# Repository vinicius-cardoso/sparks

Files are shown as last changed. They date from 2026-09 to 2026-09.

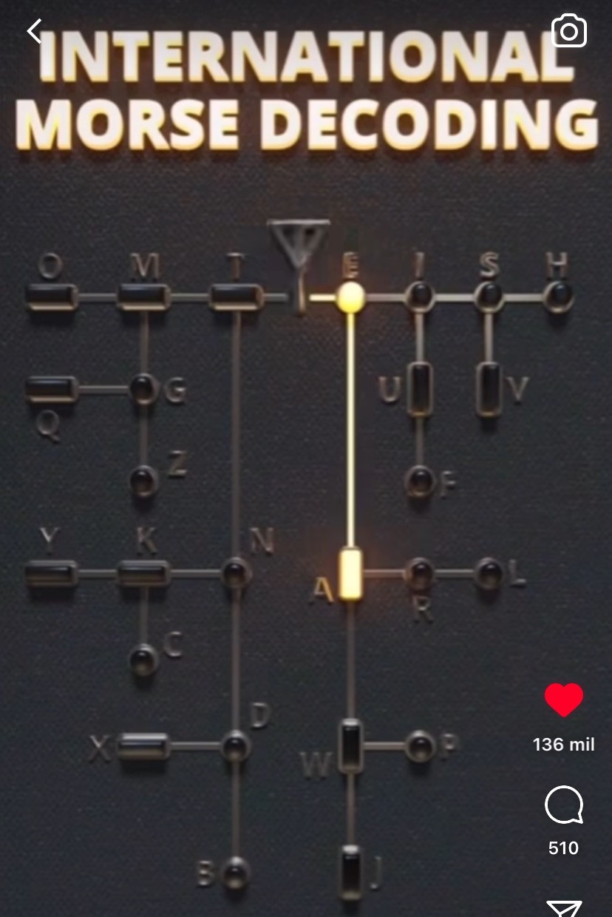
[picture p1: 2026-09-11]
media/morse_code_guide.png

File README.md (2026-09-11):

# Sparks

A handheld Morse code trainer and radio transmitter.

Press the key. The device times your dots and dashes, walks the Morse tree, and
lights the letter you just formed on a 26-LED panel shaped like the tree itself.
Optionally, it keys a CC1101 and sends the same characters over the air.

The panel is the point. Instead of showing you a decoded letter as text, Sparks
shows you *where that letter lives* in the Morse tree — so the structure of the
code becomes something you read off the board rather than something you memorize
from a table.

## The LED panel

The 26 LEDs are not an arbitrary count — they are the International Morse tree for
the English alphabet, one LED per letter. All **white**, so the panel lights
uniformly.

The dot/dash distinction is carried by the **engraved panel**, not by LED colour:
the arm joining each letter to its parent is etched as a **short mark for a dot**
or a **long bar for a dash**, exactly as in `media/morse_code_guide.png`. The code
for any letter is therefore readable by tracing its path from the centre — and
stays readable with the device switched off.

Layout also follows that image: **E** and **T** sit at the centre, **dots branch
right**, **dashes branch left**, and each deeper level branches perpendicular from
its parent.

```
level 1:  E  T                                     2 LEDs
level 2:  I  A  N  M                               4 LEDs
level 3:  S  U  R  W  D  K  G  O                   8 LEDs
level 4:  H  V  F  ·  L  ·  P  J  B  X  C  Y  Z  Q  ·  ·   12 LEDs
                                                  ──────────
                                                   26 LEDs
```

A full four-level tree has 30 slots. The four marked `·` are the non-English
letters (`..--` Ü, `.-.-` Ä, `---.` Ö, `----` CH) and are left empty — deliberate
gaps in the engraved panel, not mistakes.

## Hardware

| Part | Role |
|---|---|
| ESP32-C3 Supermini | the brain — timing, decoding, radio, everything |
| MAX7219 | LED driver — constant current, 3 pins, no series resistors |
| 26 SMD LEDs | the tree panel — all white |
| CC1101 | 433 MHz transceiver (phase 2) |
| Momentary key | Morse input |
| Buzzer | sidetone, so you hear what you send |
| Li-ion cell + TP4056 | power and charging |

The MAX7219 is **not** programmable — it has no CPU. It holds which LEDs are on
and feeds them regulated current; all decisions happen on the ESP32-C3. It exists
so the panel costs 3 GPIOs instead of 26, and so the board needs **one** current-
setting resistor instead of 26 series resistors.

### Pin budget — 11 of 13 GPIOs

| Function | Pins |
|---|---|
| MAX7219 (DIN, CLK, LOAD) | 3 |
| CC1101 (SCK, MISO, MOSI, CS, GDO0) | 5 |
| Morse key | 1 |
| Buzzer | 1 |
| Battery sense (ADC) | 1 |
| **Total** | **11 — 2 spare** |

See `docs/hardware.md` for the wiring detail and the LED addressing map.

> [!NOTE]
> The MAX7219 is a 5 V part and wants ~3.5 V for a logic high. Driving it from a
> 3.3 V ESP32-C3 often works but is marginal. See `docs/hardware.md` for the two
> fixes (level shifter, or run the chip at ~4 V).

## Build phases

1. **Trainer** — LEDs + key + buzzer. No radio. Fully useful on its own, and
   nothing about it raises regulatory questions.
2. **Radio** — populate the CC1101 once the band and power limits are settled.

The CC1101 footprint is on the board from the start; phase 1 simply leaves it
unpopulated.

## Repository layout

```text
.
├── bom/          # bill of materials
├── docs/         # design decisions, hardware notes
├── firmware/     # Arduino sketch (firmware/sparks/sparks.ino)
├── hardware/     # KiCad project, datasheets
├── mechanical/   # Onshape exports, case STEP/STL
└── media/        # reference images, photos
```

## Toolchain

- **KiCad** for the PCB (`hardware/kicad/`)
- **Onshape** for the case, exported to `mechanical/`
- **Fiber laser** to engrave the copper
- **Arduino** for firmware (`firmware/sparks/`)

Keep editable sources as the source of truth: `.kicad_pro`, `.kicad_sch`,
`.kicad_pcb`, `.ino`, native CAD. Generated manufacturing output belongs in
`exports/` directories.

## Status

Early. The existing sketch (`firmware/sparks/sparks.ino`) is a CC1101 bench test
that sends a hardcoded "HELLO" — it predates the panel design and does not yet
decode input or drive the MAX7219.

## Licence

GPL-3.0 — see `LICENSE`.

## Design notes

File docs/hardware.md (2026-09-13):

# Hardware notes

## Block diagram

```
   [KEY] ──────▶ ┌──────────────┐ ──SPI──▶ ┌─────────┐ ──▶ 26 LEDs
                 │  ESP32-C3    │          │ MAX7219 │     (tree panel)
   [BUZZER] ◀─── │  Supermini   │          └─────────┘
                 │              │               │
   [CC1101] ◀──▶ │              │            [RSET]
                 └──────────────┘
                        │
                 [battery sense]
```

The ESP32-C3 does all decision-making: key timing, dot/dash classification, tree
walking, letter identification, gap detection, radio keying, sidetone. The MAX7219
only holds LED state and regulates current — it has no CPU and cannot be
programmed.

## Pin assignment (ESP32-C3 Supermini)

The Supermini breaks out GPIO 0–10, 20, 21 — 13 usable pins.

| GPIO | Function | Notes |
|---|---|---|
| 2 | CC1101 MOSI | |
| 3 | CC1101 SCK | |
| 4 | CC1101 MISO | |
| 1 | CC1101 CS | |
| 0 | CC1101 GDO0 | |
| 5 | MAX7219 DIN | |
| 6 | MAX7219 CLK | |
| 7 | MAX7219 LOAD/CS | |
| 10 | Morse key | `INPUT_PULLUP`, active low |
| 20 | Buzzer | sidetone |
| 21 | Battery sense | ADC via divider |

**Total: 11 of 13 — 2 spare (GPIO8, GPIO9).**

GPIO8/GPIO9 are the strapping pins and the I²C defaults. They are deliberately
left free: they are the least convenient pins to commit, and keeping them open
leaves room for an I²C peripheral later.

Pin numbers above are a starting proposal — adjust during KiCad layout if routing
prefers a different assignment. Only the CC1101 SPI grouping is semi-fixed.

## Power supply — resolved

The board is powered by an **HW-357** combo module: a TP4056 charger and an
MT3608 boost converter on one board, with its own micro-USB socket.

| Module pad | Connects to |
|---|---|
| BAT+ / BAT− | the 102050 LiPo cell |
| OUT+ / OUT− | the `+5V` / `GND` nets |
| IN+ / IN− | **unused** — charging goes through the module's own micro-USB |

This settles the supply question. `+5V` is now a genuine regulated 5 V rather
than raw cell voltage, so the MAX7219 has proper headroom above the white LEDs'
~3.4 V forward drop and the panel stays at constant brightness as the battery
drains.

> [!IMPORTANT]
> The MT3608's output is set by a **trimmer potentiometer** and these boards do
> **not** ship pre-calibrated — some arrive at 10 V or higher. Set it to exactly
> 5.0 V with a multimeter, on its own, **before** connecting it to anything.
> Applying an uncalibrated output to the ESP32-C3 and MAX7219 would destroy both.

**Cost in runtime:** a boost converter draws more current than it supplies, since
it trades voltage for current. Delivering 139 mA at 5 V pulls roughly 190 mA from
a 3.7 V cell, so the 1000 mAh pack gives about 5 hours in trainer mode rather
than 7. The trade buys a panel that stays bright instead of fading.

## MAX7219 logic level — unresolved

The MAX7219 runs at 5 V and specifies `V_IH` ≈ 3.5 V. An ESP32-C3 drives 3.3 V,
which is **below spec**. It frequently works, but it is not a designed-in margin.

Two fixes, both cheap:

1. **Level shifter** on DIN / CLK / LOAD (3 lines, one small part). Keeps the chip
   at 5 V for full LED headroom.
2. **Run the MAX7219 at ~4 V**, lowering `V_IH` to ~2.8 V so 3.3 V logic is
   comfortably valid. Costs some LED drive headroom.

Option 2 is fewer parts; option 1 is more robust. Decide with the board in hand.

The **IS31FL3731** would avoid the question entirely (native 3.3 V, I²C, constant
current, same part count) — but it is SMD-only and effectively import-only in
Brazil, so it is **not** a practical fallback here. If the MAX7219 proves
troublesome at 3.3 V, add the level shifter rather than changing driver.

A suitable shifter is the **TXS0108E** or a **BSS138**-based 4-channel breakout —
both sold locally as ready-made modules.

## LED addressing map

All LEDs are white; the **Final** column records each letter's last symbol, which
is what the engraved arm must show ( · short mark / ▬ long bar ).

The MAX7219 lights whatever LED sits between a SEG and a DIG pin. Physical
position on the panel is **irrelevant** to the chip — the mapping below is
electrical only, and the panel layout follows `media/morse_code_guide.png`.

Rows are grouped by tree level, which keeps the wiring comprehensible:

| Letter | Morse | Final | Level | DIG | SEG |
|---|---|---|---|---|---|
| E | `.` | dot · | 1 | 0 | 0 |
| T | `-` | dash ▬ | 1 | 0 | 1 |
| I | `..` | dot · | 2 | 1 | 0 |
| A | `.-` | dash ▬ | 2 | 1 | 1 |
| N | `-.` | dot · | 2 | 1 | 2 |
| M | `--` | dash ▬ | 2 | 1 | 3 |
| S | `...` | dot · | 3 | 2 | 0 |
| U | `..-` | dash ▬ | 3 | 2 | 1 |
| R | `.-.` | dot · | 3 | 2 | 2 |
| W | `.--` | dash ▬ | 3 | 2 | 3 |
| D | `-..` | dot · | 3 | 2 | 4 |
| K | `-.-` | dash ▬ | 3 | 2 | 5 |
| G | `--.` | dot · | 3 | 2 | 6 |
| O | `---` | dash ▬ | 3 | 2 | 7 |
| H | `....` | dot · | 4 | 3 | 0 |
| V | `...-` | dash ▬ | 4 | 3 | 1 |
| F | `..-.` | dot · | 4 | 3 | 2 |
| L | `.-..` | dot · | 4 | 3 | 4 |
| P | `.--.` | dot · | 4 | 3 | 6 |
| J | `.---` | dash ▬ | 4 | 3 | 7 |
| B | `-...` | dot · | 4 | 4 | 0 |
| X | `-..-` | dash ▬ | 4 | 4 | 1 |
| C | `-.-.` | dot · | 4 | 4 | 2 |
| Y | `-.--` | dash ▬ | 4 | 4 | 3 |
| Z | `--..` | dot · | 4 | 4 | 4 |
| Q | `--.-` | dash ▬ | 4 | 4 | 5 |

Uses DIG0–DIG4 (5 of 8) and SEG0–SEG7. Gaps at DIG3/SEG3, DIG3/SEG5, DIG4/SEG6,
DIG4/SEG7 are the four non-English letters — left unpopulated.

Three DIG lines remain free, so status LEDs (power, TX, charge) can be added later
with no driver change.

## KiCad reference

Verified against the KiCad 10.0.5 stock libraries.

### Symbols available

| Part | Library | Symbol |
|---|---|---|
| MAX7219 | `Driver_LED` | `MAX7219` |
| Battery cell | `Device` | `Battery_Cell` |
| LED / resistor / capacitor | `Device` | `LED` / `R` / `C` |

### Symbols NOT in the stock libraries

These are all boards mounted on headers rather than bare chips, so represent each
with a `Connector_Generic:Conn_01x0N` sized to its pin count:

- **ESP32-C3 Supermini** — stock libs carry only the bare die and the WROOM
  modules, not this board. Two 8-pin headers match its layout.
- **TP4056** — stock libs contain **TP4057**, a *different part*; do not
  substitute it. Use the local `TP4056-Breakout` library instead.
- **CC1101 module** — socketed, not soldered. Use a generic
  `Connector_Generic:Conn_02x04_Odd_Even` symbol with the footprint
  `Connector_PinSocket_2.54mm:PinSocket_2x04_P2.54mm_Vertical`. No dedicated
  symbol is kept: the board only carries the socket, so a generic connector
  describes it accurately.

### Footprints

| Part | Footprint |
|---|---|
| MAX7219 | `Package_DIP:DIP-24_W7.62mm` |
| White LEDs (×26) | `LED_SMD:LED_0805_2012Metric_Pad1.15x1.40mm_HandSolder` |
| Resistors / caps | `Resistor_SMD:R_0805_2012Metric_Pad1.20x1.40mm_HandSolder` |

Two things to get right:

- Use **`W7.62mm`** (300 mil narrow body), *not* the `W15.24mm` variants — those
  are a physically different package.
- Prefer the **`_HandSolder`** variants throughout; their pads are slightly
  extended for manual soldering.

### MAX7219 pinout, and a naming trap

The symbol names the segment outputs `SEG_A`…`SEG_G` plus `SEG_DP`, because the
chip was designed for seven-segment displays. For Sparks they are just eight
generic outputs. Mapping to the addressing table above:

| Table | Symbol pin | Pin № |
|---|---|---|
| SEG0 | `SEG_A` | 14 |
| SEG1 | `SEG_B` | 16 |
| SEG2 | `SEG_C` | 20 |
| SEG3 | `SEG_D` | 23 |
| SEG4 | `SEG_E` | 21 |
| SEG5 | `SEG_F` | 15 |
| SEG6 | `SEG_G` | 17 |
| SEG7 | `SEG_DP` | 22 |

`DIG_0`…`DIG_7` map directly; Sparks uses DIG_0–DIG_4.

**Pin 18 is `ISET`** — this is `RSET` elsewhere in these notes. It connects to
**V+**, not to ground.

### Connections

```
ESP32-C3           MAX7219
GPIO5  ──────────▶ DIN   (pin 1)
GPIO6  ──────────▶ CLK   (pin 13)
GPIO7  ──────────▶ LOAD  (pin 12)
                   ISET  (pin 18) ──[RSET]── V+
                   V+    (pin 19) ── 5 V
                   GND   (pins 4 AND 9)
```

LED **anodes → SEG** pins, **cathodes → DIG** pins.

> [!WARNING]
> Connect **both** ground pins (4 and 9). Leaving one floating is a common
> omission and causes erratic, hard-to-diagnose behaviour.

## Panel layout and engraving

From `media/morse_code_guide.png`:

- **E** and **T** at the centre, flanking the root.
- **Dots branch right**, **dashes branch left**.
- Each deeper level branches perpendicular from its parent, producing the
  cross/grid arrangement rather than a conventional top-down tree.
- Engraved arms connect parent to child, so the path spelling each letter is
  physically traceable on the panel.

### The arms carry the dot/dash information

Since the LEDs are all white, the engraving is now the **only** thing encoding
dot vs dash — so it has to be unambiguous:

- a **dot** arm is engraved as a short mark ( · )
- a **dash** arm is engraved as a long bar ( ▬ )

This matches the reference image, where the arms are visibly different lengths.
Make the long bar at least 3× the short mark, mirroring Morse timing itself, so
the difference is obvious at a glance rather than something to measure.

Each letter is also labelled. Tracing from the centre outward and reading the arms
gives the letter's code directly — and unlike LED colour, it stays readable with
the device switched off, which makes the panel useful as a static reference chart.

## CC1101 module and antenna

The module on hand is the **V2.0 SMA variant**, marked `433M`, with a gold SMA
female socket on the board edge. It ships with a short black whip antenna carrying
a male SMA plug, which **screws onto** that socket.

The antenna is therefore **detachable, not built in** — the two simply come in the
same bag. Nothing to buy, but the mechanical design has to account for it:

- The SMA socket sticks out from the module's edge and is rigid. It sets a hard
  constraint on where the CC1101 can sit inside the case.
- The case needs either an opening for the whip, or an internal antenna position
  with the whip removed. Antennas do not work well inside a sealed enclosure,
  especially near a copper ground plane.
- A panel-mount SMA extension (pigtail) is the usual fix: socket on the case wall,
  short coax to the module. Adds a part but frees the module's placement.
- The whip is removable, so it can be unscrewed for storage — worth designing for
  if the device is meant to be pocketable.

**Never key the transmitter with the antenna unscrewed.** With nothing to radiate
into, power reflects back into the PA and can damage it. For bench testing without
emitting, use a 50 Ω dummy load in place of the whip.

## LEDs — all white

All 26 LEDs are white. This was a deliberate simplification: a single colour means
a single Vf and a single efficiency, so the one `RSET` the MAX7219 allows suits
every LED and the panel lights uniformly.

(The earlier design used 14 red + 12 green to encode each letter's final symbol.
That mapping is still *true* — see `docs/decisions.md` §1 for why the count is 26
— but it is now expressed by the engraved panel rather than by LED colour.)

**Sourcing:** buy all 26 from a single reel or batch. Bin-to-bin variation within
one colour is small but visible on a panel where LEDs sit side by side.

> [!IMPORTANT]
> White LEDs have a **high forward voltage: ~2.8–3.4 V**, considerably more than a
> red LED's ~2.0 V. This bears directly on the MAX7219 supply question in
> *MAX7219 logic level* above — the chip needs headroom above Vf to drive current
> properly. It argues for running the MAX7219 at **5 V** rather than the ~4 V
> option, which in turn makes the level shifter on DIN/CLK/LOAD the likely choice.
> Verify on the breadboard before committing to either.

## Power budget

Estimated worst case. The MAX7219 multiplexes one digit row at a time, so the
instantaneous draw is set by the **largest row**, not by all 26 LEDs at once.

| Digit row | LEDs | Peak @20 mA/LED |
|---|---|---|
| DIG0 | 2 | 40 mA |
| DIG1 | 4 | 80 mA |
| DIG2 | 8 | **160 mA** ← worst row |
| DIG3 | 6 | 120 mA |
| DIG4 | 6 | 120 mA |

- **Worst instantaneous:** ~160 mA (DIG2, the level-3 row — all 8 letters)
- **Average panel draw, everything "lit":** ~104 mA at 20% duty per row

Adding the rest:

| Load | Draw |
|---|---|
| Panel (average) | ~104 mA |
| ESP32-C3 active | ~30 mA |
| MAX7219 quiescent | ~5 mA |
| CC1101 TX @ 10 dBm | ~35 mA |
| Buzzer | ~20 mA |

- **Trainer mode (no radio): ~139 mA**
- **TX mode (worst case): ~194 mA**

### Battery sizing

| Cell | Trainer | TX |
|---|---|---|
| 500 mAh pouch | 3.6 h | 2.6 h |
| 1000 mAh pouch | 7.2 h | 5.2 h |
| 18650 2000 mAh | 14.4 h | 10.3 h |
| 18650 3000 mAh | 21.6 h | 15.5 h |

These are pessimistic — they assume the panel is fully lit continuously, which it
never is. In real use only a few LEDs light at a time and the device sleeps
between key presses, so expect substantially better. **Any cell ≥1000 mAh is
comfortable**; pick on physical size for the case rather than on capacity.

Lowering `RSET` to run the LEDs at 10 mA instead of 20 mA roughly halves the panel
draw and is likely still plenty bright indoors.

## Power

- Li-ion cell (18650 or pouch) + TP4056 charge module with protection.
- ESP32-C3 Supermini has an onboard regulator and accepts battery voltage at 5V/VIN.
- MAX7219 supply depends on the logic-level decision above.
- Battery sense: resistor divider into an ADC pin. Size it so the divider current
  is negligible, and consider a MOSFET to disconnect it during sleep.

## Fabrication

Copper engraved with a fiber laser. Relevant consequences:

- Trace count matters more than usual — every trace is engraving time and a
  potential defect. The MAX7219 keeps this to ~16 panel traces.
- **MAX7219 package: DIP-24**, chosen for soldering ease. Pin pitch is 2.54 mm
  against SOIC-24's 1.27 mm, the pads are large, and through-hole joints are
  soldered from the underside with room to work — solder bridges are very hard to
  create. This also sidesteps needing to characterise the laser's minimum
  trace/space, since 2.54 mm is comfortable for any fiber laser.
- Cost: the DIP body is ~32 × 8 mm and needs 24 drilled holes. Acceptable here
  because the 26-LED tree already sets the board size, not the driver IC.
- The **LEDs remain SMD** (0805). They are simple two-pad parts — much easier than
  a fine-pitch IC — and SMD keeps them flush against the panel surface, which
  matters for how the engraved tree reads.

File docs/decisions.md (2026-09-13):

# Design decisions

A record of what was chosen, what was rejected, and why. Written so the reasoning
survives — if a decision gets revisited, the tradeoff is here rather than being
re-derived from scratch.

## 1. The 26 LEDs are the Morse tree

**Decision:** one LED per letter, arranged as the dichotomic Morse tree from
`media/morse_code_guide.png`. **All LEDs white** (revised — see §1a).

A full four-level tree holds 30 letters; the 4 unused slots (`..--`, `.-.-`,
`---.`, `----`) are non-English letters and stay empty on the panel.

### Where the number 26 came from

The original specification was 14 red + 12 green, and those counts turned out to
be exact rather than arbitrary. Colouring each letter by its **final** symbol
splits the English alphabet precisely:

- dot-final, 14: `B C D E F G H I L N P R S Z`
- dash-final, 12: `A J K M O Q T U V W X Y`

This is what identified the panel as the Morse tree in the first place, and it
still explains why there are 26 LEDs. The relationship is real; only its *visual
expression* changed in §1a.

**Why the shape matters:** the panel's arrangement is the teaching mechanism. Any
option that forced a different physical layout was rejected on that basis alone.

## 1a. Revised: all LEDs white, dot/dash engraved instead

**Decision:** all 26 LEDs white; the dot/dash distinction moves from LED colour
to the **engraved arms** — short mark for a dot, long bar for a dash.

**Why:**

- **One colour, one `RSET`.** The MAX7219 allows a single current-setting resistor
  for all LEDs. Red (~2.0 V) and green (~2.0–3.2 V) differ in Vf and efficiency, so
  under one `RSET` they would not have matched in brightness — and per-digit
  intensity control could not fix it, since the colours were mixed across rows.
  A single colour eliminates the problem entirely.
- **Simpler sourcing.** One part number, one reel, uniform output.
- **The information is not lost.** Engraving carries it permanently, and unlike LED
  colour it is readable with the device switched off — so the panel doubles as a
  static reference chart.

**Tradeoff accepted:** no at-a-glance colour cue for "this letter ends long". The
engraved arm lengths convey it instead, which requires tracing rather than
glancing.

**Consequence to watch:** white LEDs have a high forward voltage (~2.8–3.4 V),
which pushes toward running the MAX7219 at 5 V for headroom — and therefore toward
needing the level shifter. See `docs/hardware.md`.

## 2. Some LED driver is mandatory — this is arithmetic, not preference

Fixed peripheral cost is 8 pins (CC1101 SPI ×4 + GDO0, key, buzzer, battery ADC).
Against that:

| Board | GPIO | Free after peripherals | Direct 26 LEDs? |
|---|---|---|---|
| ESP32-C3 Supermini | 13 | 5 | no — short 21 |
| Arduino Nano | 20 | 12 | no — short 14 |
| Raspberry Pi Pico | 26 | 18 | no — short 8 |
| ESP32 DevKit V1 | 25 | 17 | no — short 9 |

**No board on hand can drive 26 LEDs directly**, not even the Pico. Switching
boards does not dissolve the constraint, which is why the MCU choice was freed to
be decided on other merits.

## 3. Driver: MAX7219

Ranked by **physical build work** (firmware cost excluded — it's written, not
soldered):

| Option | Parts to place | Joints | Brightness |
|---|---|---|---|
| **MAX7219** | **4** | 82 | full, dimmable |
| Pico charlieplex | 6 | 64 | dim — 3.8% duty |
| 4× 74HC595 | 34 | 176 | full |
| WS2812B | 52 | 156 | full |

**Chosen: MAX7219.** Constant-current drive means **one** `RSET` resistor sets
brightness for all 26 LEDs, eliminating 26 series resistors — 26 fewer parts to
place *and* 26 fewer traces to route and laser-etch.

**Rejected:**

- **74HC595 ×4** — was the initial recommendation while firmware simplicity still
  counted as a cost. Once firmware became free, 34 parts vs 4 ended it. Still a
  reasonable fallback: easier to source, and already stocked locally.
- **Charlieplexing** — 6 pins for 30 LEDs and the fewest parts, but lights one LED
  at a time: 3.8% duty. Matching a static 5 mA LED would need ~130 mA peak against
  an ~8 mA/pin RP2040 spec. For a device whose whole purpose is *being read*, a dim
  panel is disqualifying.
- **WS2812B** — one pin and per-LED colour in software, but abandons the specified
  red/green SMD LEDs, needs a decoupling cap per LED (52 parts), and draws far more
  from the battery.

### Clarification worth keeping

"Matrix" here means the **electrical addressing scheme** (which SEG/DIG pin pair
addresses each LED), *not* a physical square. The MAX7219 exposes 8 SEG + 8 DIG
pins and lights whatever LED sits between a pair — it has no knowledge of where
that LED physically sits. The tree layout is therefore completely unconstrained by
the driver choice.

The off-the-shelf "8×8 MAX7219 module" is a *product built around* the chip, with
LEDs pre-soldered in a grid. Not what is used here — Sparks uses the bare IC.

## 4. Board: ESP32-C3 Supermini

Every candidate fits once a driver is used, so this was decided on other grounds:

- **3.3 V native** — wires directly to the CC1101. The Arduino Nano is 5 V and
  would need level shifting on every SPI line to avoid damaging the radio.
- **Smallest footprint** for a handheld case.
- **USB-C**, good deep sleep for Li-ion.
- The existing sketch already targets it.

**Rejected:** Pico (only compelling for charlieplexing, which lost on brightness;
larger board), ESP32 DevKit V1 (largest, worst idle current), Nano (5 V mismatch).

## 5. No OLED

The existing bench sketch drives an SSD1306, but the 26-LED tree *is* the display.
Dropping it removes a part, a case cutout, and frees GPIO8/GPIO9 — the strapping
pins, which are the least convenient pins to spend anyway.

**Tradeoff accepted:** no text readout, so no WPM, battery percentage, or decoded
letter as an actual character. Reading the tree is the intended skill.

## 6. Radio: trainer first

Phase 1 ships without RF. The CC1101 footprint is on the board but unpopulated,
so the trainer is immediately buildable and usable while band and power limits are
settled separately.

**Open:** the legal position for 433 MHz short-range transmission in Brazil
(ANATEL) has not been researched yet. Do that before populating the radio.

## 7. CC1101 antenna is detachable, not built in

**Finding, not a decision:** the module on hand is the **V2.0 SMA variant** (gold
SMA socket on the board edge, `433M` silkscreen). It ships with a short whip
carrying a male SMA plug, which screws on. The two arrive in the same bag, which
is easy to read as "the antenna is built in" — it is not.

**Consequences:** nothing to buy, but the whip is a rigid protruding part that
constrains where the CC1101 can sit in the case, and antennas work poorly inside a
sealed enclosure next to a copper ground plane. A panel-mount SMA pigtail is the
usual fix. See `docs/hardware.md`.

**Safety:** never key the transmitter with the whip unscrewed — power reflects back
into the PA. Use a 50 Ω dummy load for bench testing.

## 8. The panel needs a double-sided board

**Finding.** Routing the 26-LED matrix on a single layer requires roughly **56
jumper wires**, measured by taking each net's minimum spanning tree and counting
straight-line crossings between nets.

**Why.** The matrix is organised by tree *level* — DIG0 is level 1, DIG3 holds
six of the level-4 letters — while the panel is organised by tree *geometry*,
where those same six letters (J, P, F, L, V, H) sit scattered across four rows on
opposite sides of the board. The electrical grouping and the visual arrangement
are different organisations of the same 26 parts, and they do not reconcile on
one layer.

Total net length is about 823 mm across 13 nets.

**Decision:** route double-sided. DIG nets on the back under the panel, SEG nets
on the front between the LEDs, crossings resolved with vias rather than soldered
jumpers. The MAX7219 mounts on the back, centred beneath the panel, which also
shortens its 16 traces.

**Rejected:** single-sided with jumpers — 25-30 hand-soldered wires even after
optimisation, on the visible face of a handheld device. Rejected on both build
effort and appearance.

**Also rejected:** rearranging the panel so electrical rows match visual rows.
That would route trivially on one layer but abandons the tree shape, which is the
device's entire purpose.

**Consequence for fabrication:** the fiber laser must etch both faces with
registration between them. Add alignment holes to the board outline before
etching.

## Open items

- **MAX7219 at 3.3 V.** The chip is a 5 V part wanting ~3.5 V for a logic high.
  Often works directly from a 3.3 V MCU; not reliable enough to design around. Fix
  with a level shifter on DIN/CLK/LOAD, or run the chip at ~4 V. Decide with the
  real board in hand. The **IS31FL3731** was the considered alternative — natively
  3.3 V, I²C, same part count — but MAX7219 was chosen for availability.
- **ANATEL limits** for 433 MHz (see §6).
- **LED forward voltage** vs MAX7219 headroom — check once the exact LEDs are
  picked, since it sets `RSET`.

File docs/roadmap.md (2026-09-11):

# Roadmap

Ordered so that each step produces something testable, and so the parts that are
still undecided stay off the critical path.

## Phase 0 — settle the unknowns (no hardware needed)

- [ ] Pick the exact white LEDs; record Vf. Buy all 26 from one reel/batch.
      **White Vf is high (~2.8–3.4 V) — check MAX7219 supply headroom.**
- [ ] Compute `RSET` from Vf and target current.
- [ ] Design the engraved arms: short mark = dot, long bar = dash, ≥3:1 ratio.
      With white LEDs this engraving is the *only* dot/dash cue.
- [x] Estimate worst-case current → see `docs/hardware.md` § Power budget.
      Trainer ~139 mA, TX ~194 mA worst case; any cell ≥1000 mAh is comfortable.
- [ ] Decide MAX7219 supply voltage → level shifter required or not.
- [x] MAX7219 package → **DIP-24**, chosen for hand-soldering ease. 2.54 mm pitch
      is within any fiber laser's capability, so the minimum trace/space question
      no longer blocks the design.

## Phase 1 — breadboard the panel

- [ ] MAX7219 + a handful of LEDs on a breadboard, driven by the ESP32-C3.
- [ ] Confirm 3.3 V logic actually clocks the chip reliably (this is the open risk).
- [ ] Firmware: light an arbitrary LED by letter — proves the SEG/DIG map.

## Phase 2 — the trainer firmware

- [ ] Key timing: debounce, classify dot vs dash by duration.
- [ ] Walk the tree as symbols arrive; light the current node live.
- [ ] Letter gap → commit the letter. Word gap → space.
- [ ] Buzzer sidetone keyed with the input.
- [ ] Adaptive timing, so the dot/dash threshold follows the user's speed.

At this point Sparks is fully useful without a PCB or a radio.

## Phase 3 — PCB

- [ ] Schematic in KiCad.
- [ ] Panel layout matching `media/morse_code_guide.png` — this is the hard part;
      the LED positions are fixed by the tree, routing works around them.
- [ ] Route; keep trace count low for the laser.
- [ ] Engrave, populate, test.

## Phase 4 — case

- [ ] Onshape model around the finished board.
- [ ] Front panel with the tree engraved — arms connecting parent to child.
- [ ] Export STEP/STL to `mechanical/`.

## Phase 5 — radio

- [ ] Research ANATEL limits for 433 MHz short-range in Brazil. **Blocking.**
- [ ] Populate the CC1101; test into a dummy load first.
- [ ] Key the radio in step with the LED panel and sidetone.
- [ ] Decide on a receive mode — decoding incoming Morse onto the same panel would
      be a natural extension.

## Ideas, unscheduled

- Playback mode: the device sends a letter, you copy it — reverse training.
- Speed/WPM readout using the spare DIG lines as a small status row.
- Store practice statistics; which letters you get wrong most.

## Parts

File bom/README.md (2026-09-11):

# Bill of materials

`bom.csv` is the working BOM. Columns:

- **status** — `have` / `to buy` / `to make` / `conditional` / `phase 2`
- **notes** — anything that would otherwise be lost between sessions

## Sourcing: Brazil

Parts are chosen to be buyable locally (Mercado Livre, national distributors)
rather than imported. This is a selection criterion, not an afterthought — a part
that is optimal on paper but import-only costs weeks and customs hassle.

**Consequences already baked into this BOM:**

- **MAX7219 in DIP-24**, not SOIC. The DIP is the common hobby part sold
  everywhere here; the SMD version is the awkward one to find. (DIP was already
  chosen for soldering ease — the two criteria agree.)
- **IS31FL3731 rejected as a fallback.** Technically the better driver, but
  SMD-only and effectively import-only. If the MAX7219 struggles at 3.3 V, add a
  level shifter instead of changing driver.
- **Level shifter named explicitly** — TXS0108E or a BSS138 breakout, both sold
  locally as ready-made modules.

**Watch out for:** the 26 white 0805 LEDs. Buying locally often means loose parts
from mixed bins rather than one reel, and bin-to-bin variation is visible when the
LEDs sit side by side on a panel. Buy 40–50 from a **single seller and lot**, then
pick the 26 most consistent. The spares also cover soldering mishaps.

## Things to resolve before ordering

1. **LED forward voltage.** Sets `RSET` (R1) and therefore panel brightness. Red
   and green differ, and the MAX7219 uses one `RSET` for all — so the two colours
   will not match in brightness by default. Check Vf for both and decide whether
   the mismatch is acceptable or needs compensating.
2. **Total current with all 26 lit.** Sets battery capacity. Not yet estimated.
3. **MAX7219 package.** DIP-24 is far easier to fiber-laser than SOIC-24. Confirm
   the minimum pitch the laser holds before committing.
4. **Logic level.** If the MAX7219 runs at 5 V, the level shifter becomes
   required, not conditional. See `docs/hardware.md`.

## Phase 1 vs phase 2

Phase 1 (trainer) needs everything except U3 (CC1101) and J1 (antenna). The radio
footprint is on the board from the start and simply stays unpopulated, so phase 1
is buildable without settling any regulatory question.

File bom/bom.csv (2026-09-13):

ref | qty | part | value | package | role | status | notes
U1 | 1 | ESP32-C3 Supermini |  | module | MCU — all timing/decoding/radio control | have | 13 GPIO broken out (0-10 20 21); 3.3V native
U2 | 1 | MAX7219 |  | DIP-24 | LED driver — constant current 3-wire | to buy | DIP chosen for hand-soldering: 2.54mm pitch vs 1.27mm SOIC. 5V part; see docs/hardware.md logic-level note
U3 | 1 | CC1101 module V2.0 | 433 MHz | module + SMA socket | RF transceiver | have | phase 2; SMA variant with detachable whip. SOCKETED not soldered — plugs into J2 when radio is in use
J2 | 1 | Pin socket 2x4 female | 2.54mm | PinSocket_2x04_P2.54mm_Vertical | CC1101 module socket | to buy | female socket on the PCB; module's male pins plug in. Symbol: Conn_02x04_Odd_Even (generic — no dedicated CC1101 symbol needed)
D1-D26 | 26 | SMD LED white |  | 0805 | one per letter of the Morse tree | to buy | ALL WHITE — single Vf so one RSET suits every LED. BUY EXTRA (40-50) FROM ONE SELLER/LOT — mixed bins show as uneven brightness side by side. White Vf ~2.8-3.4V — check MAX7219 headroom.
R1 | 1 | Resistor | ~10k | 0805 | RSET — sets LED current for ALL 26 LEDs | to buy | exact value depends on LED Vf and target brightness
R2 | 1 | Resistor | 220k | 0805 | battery divider high side | to buy | battery divider high side; R2=R3 halves Vbat into ADC range. 220k => ~9.5uA drain
R3 | 1 | Resistor | 220k | 0805 | battery divider low side | to buy | battery divider low side; midpoint to GPIO21. Keep <500k or ADC reads drift
C1 | 1 | Capacitor | 100nF | 0805 | MAX7219 decoupling | to buy | place close to the IC
C2 | 1 | Capacitor | 10uF | 0805 | MAX7219 bulk | to buy
C3 | 1 | Capacitor | 100nF | 0805 | ESP32-C3 decoupling | to buy
SW1 | 1 | Tactile switch 6x6mm |  | SW_PUSH_6mm (THT, 4-pin) | Morse key | to buy | classic 6x6 tact switch; 4 pins but only 2 nets. Pick _H5mm variant if button height matters for the case
SW2 | 1 | Slide switch |  | SMD | power on/off | to buy
BZ1 | 1 | Magnetic buzzer 12mm |  | Buzzer_12x9.5RM7.6 (THT) | sidetone — hear what you send | to buy | 12mm dia, 9.5mm tall, 7.6mm pin pitch. ACTIVE buzzer = fixed tone; PASSIVE needed for tone() sidetone — see docs
BT1 | 1 | LiPo pouch 102050 | 3.7V 1000mAh | SolderWire 1x02 P3.7mm (flying leads) | power | to buy | 10x20x50mm, 1000mAh = ~5h trainer / ~3.5h TX via boost (boost draws ~190mA from cell for 139mA at 5V). Flying leads soldered to pads; use _Relief variant for strain relief
M1 | 1 | HW-357 TP4056+MT3608 module | 5V out | module w/ micro-USB | charging + protection + 5V boost | have | combo board: TP4056 charger + MT3608 boost. Charge via its own micro-USB; IN+/IN- unused. SET TRIMMER TO 5.0V BEFORE CONNECTING - ships uncalibrated
J1 | 1 | Antenna whip | 433 MHz | SMA male stub | RF | have | ships with the module; screws onto the board SMA socket. Detachable — case needs an opening. Never key the radio without it or a dummy load.
 | 1 | Level shifter TXS0108E or BSS138 |  | breakout module | 3.3V to 5V for MAX7219 DIN/CLK/LOAD | conditional | only if running MAX7219 at 5V — see docs/hardware.md. Both sold as modules in BR
 | 1 | PCB |  |  | main board | to make | fiber-laser engraved copper
 | 1 | Enclosure |  |  | case | to make | Onshape; exports to mechanical/

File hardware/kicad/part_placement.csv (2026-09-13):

ref | x_mm | y_mm | rot | layer | note
J1 | 150.0 | 100.0 | 90 | front | CC1101 socket at top edge, ROT 90 so the 4-pin row runs along X and the antenna points UP away from user
U1 | 150.0 | 129.0 | 0 | back | MAX7219 on back, centred under panel
R1 | 132.0 | 156.0 | 0 | back | RSET, back
C1 | 135.0 | 156.0 | 0 | back | 100nF MAX7219, back
C2 | 138.0 | 156.0 | 0 | back | 10uF bulk, back
BZ1 | 129.0 | 161.0 | 0 | front | buzzer
BT1 | 176.0 | 157.0 | 0 | front | battery pads
R2 | 168.0 | 157.0 | 0 | front | battery divider
R3 | 171.0 | 157.0 | 0 | front | battery divider
C3 | 150.0 | 157.0 | 0 | front | 100nF ESP32
U2 | 137.0 | 180.0 | 0 | front | ESP32-C3
J2 | 168.0 | 175.0 | 0 | front | HW-357 power module
SW1 | 155.0 | 188.0 | 0 | front | Morse key

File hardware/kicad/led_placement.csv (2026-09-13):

ref | letter | morse | x_mm | y_mm | dig | seg
D1 | E | . | 150.00 | 108.00 | 0 | 0
D2 | T | - | 142.00 | 108.00 | 0 | 1
D3 | I | .. | 158.00 | 108.00 | 1 | 0
D4 | A | .- | 150.00 | 129.00 | 1 | 1
D5 | N | -. | 142.00 | 129.00 | 1 | 2
D6 | M | -- | 134.00 | 108.00 | 1 | 3
D7 | S | ... | 166.00 | 108.00 | 2 | 0
D8 | U | ..- | 158.00 | 115.00 | 2 | 1
D9 | R | .-. | 158.00 | 129.00 | 2 | 2
D10 | W | .-- | 150.00 | 143.00 | 2 | 3
D11 | D | -.. | 142.00 | 143.00 | 2 | 4
D12 | K | -.- | 134.00 | 129.00 | 2 | 5
D13 | G | --. | 134.00 | 115.00 | 2 | 6
D14 | O | --- | 126.00 | 108.00 | 2 | 7
D15 | H | .... | 174.00 | 108.00 | 3 | 0
D16 | V | ...- | 166.00 | 115.00 | 3 | 1
D17 | F | ..-. | 158.00 | 122.00 | 3 | 2
D18 | L | .-.. | 166.00 | 129.00 | 3 | 4
D19 | P | .--. | 158.00 | 143.00 | 3 | 6
D20 | J | .--- | 150.00 | 150.00 | 3 | 7
D21 | B | -... | 142.00 | 150.00 | 4 | 0
D22 | X | -..- | 134.00 | 143.00 | 4 | 1
D23 | C | -.-. | 134.00 | 136.00 | 4 | 2
D24 | Y | -.-- | 126.00 | 129.00 | 4 | 3
D25 | Z | --.. | 134.00 | 122.00 | 4 | 4
D26 | Q | --.- | 126.00 | 115.00 | 4 | 5

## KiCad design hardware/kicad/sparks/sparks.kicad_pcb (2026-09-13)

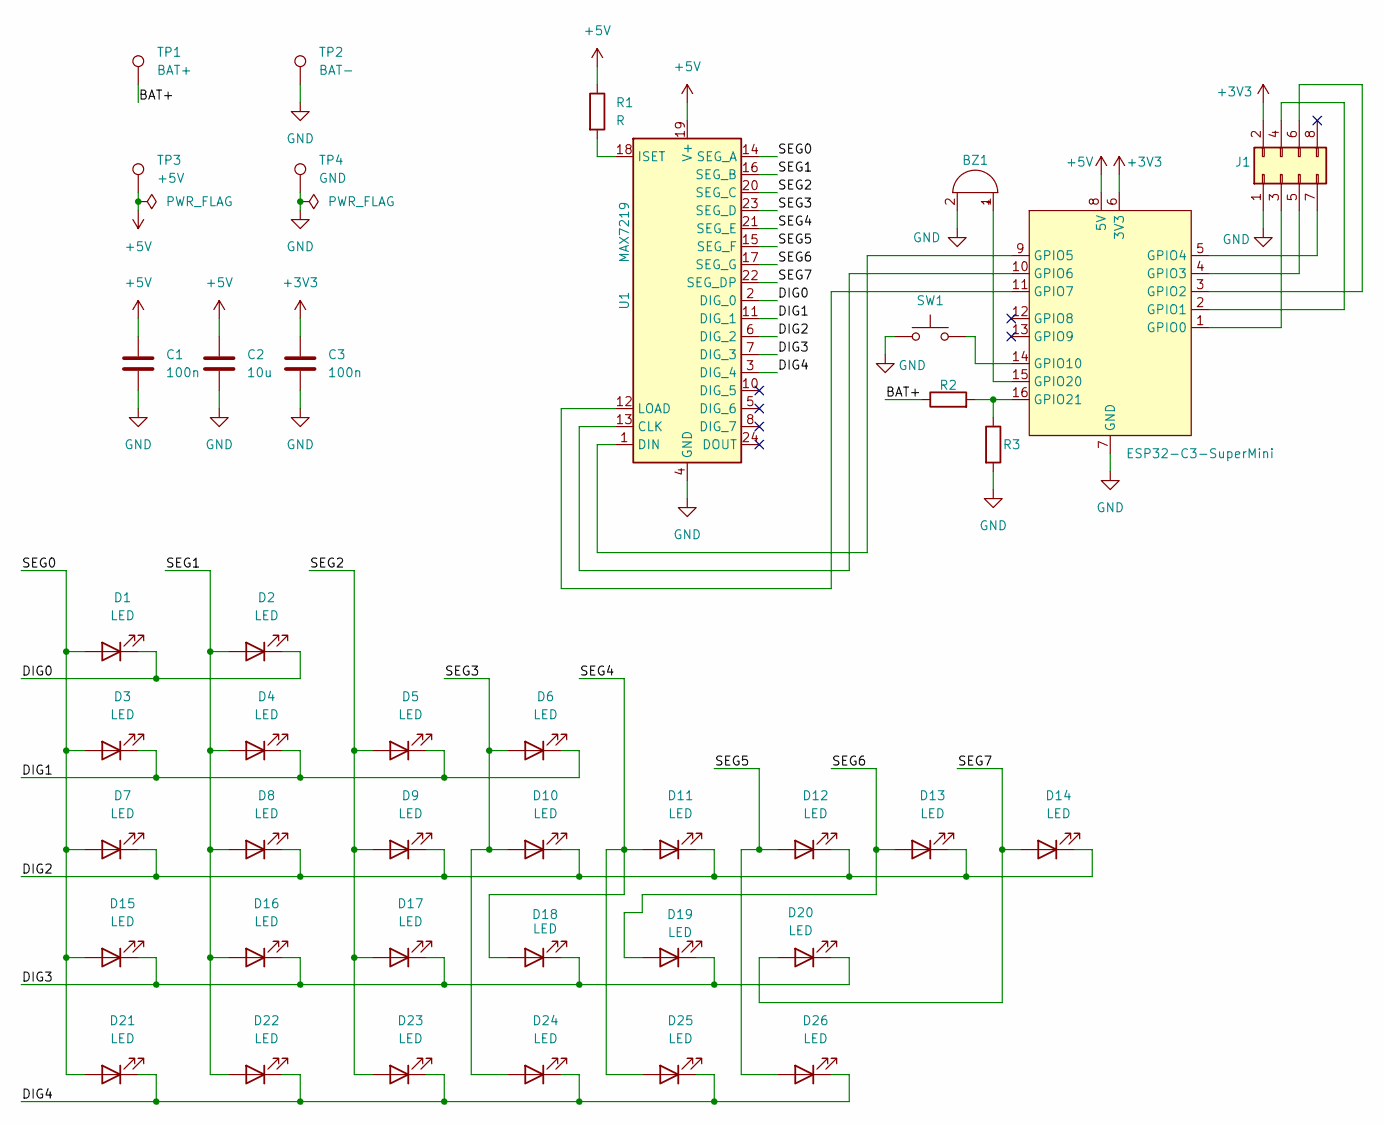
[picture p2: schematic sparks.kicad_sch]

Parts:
BZ1: Buzzer; Buzzer_12x9.5RM7.6
C1, C3: 100n; C_0805_2012Metric_Pad1.18x1.45mm_HandSolder
C2: 10u; C_0805_2012Metric_Pad1.18x1.45mm_HandSolder
D1, D2, D3, D4, D5, D6, D7, D8, D9, D10, D11, D12, D13, D14, D15, D16, D17, D18, D19, D20, D21, D22, D23, D24, D25, D26: LED; LED_0805_2012Metric_Pad1.15x1.40mm_HandSolder
J1: Conn_02x04_Odd_Even; PinHeader_2x04_P2.54mm_Vertical
R1: R; R_0805_2012Metric_Pad1.20x1.40mm_HandSolder
R2, R3: 220k; R_0805_2012Metric_Pad1.20x1.40mm_HandSolder
SW1: SW_Push; SW_PUSH_6mm
TP1: BAT+; TestPoint_THTPad_2.0x2.0mm_Drill1.0mm
TP2: BAT-; TestPoint_THTPad_2.0x2.0mm_Drill1.0mm
TP3: +5V; TestPoint_THTPad_2.0x2.0mm_Drill1.0mm
TP4: GND; TestPoint_THTPad_2.0x2.0mm_Drill1.0mm
U1: MAX7219; SOIC-24W_7.5x15.4mm_P1.27mm
U2: ESP32-C3-SuperMini

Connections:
+3V3: C3.1, J1.2, U2.6 (3V3)
+5V: C1.1, C2.1, R1.1, TP3.1 (1_1), U1.19 (V+), U2.8 (5V)
/BAT+: R2.1, TP1.1 (1_1)
/DIG0: D1.1 (K), D2.1 (K), U1.2 (DIG_0)
/DIG1: D3.1 (K), D4.1 (K), D5.1 (K), D6.1 (K), U1.11 (DIG_1)
/DIG2: D7.1 (K), D8.1 (K), D9.1 (K), D10.1 (K), D11.1 (K), D12.1 (K), D13.1 (K), D14.1 (K), U1.6 (DIG_2)
/DIG3: D15.1 (K), D16.1 (K), D17.1 (K), D18.1 (K), D19.1 (K), D20.1 (K), U1.7 (DIG_3)
/DIG4: D21.1 (K), D22.1 (K), D23.1 (K), D24.1 (K), D25.1 (K), D26.1 (K), U1.3 (DIG_4)
/SEG0: D1.2 (A), D3.2 (A), D7.2 (A), D15.2 (A), D21.2 (A), U1.14 (SEG_A)
/SEG1: D2.2 (A), D4.2 (A), D8.2 (A), D16.2 (A), D22.2 (A), U1.16 (SEG_B)
/SEG2: D5.2 (A), D9.2 (A), D17.2 (A), D23.2 (A), U1.20 (SEG_C)
/SEG3: D6.2 (A), D10.2 (A), D24.2 (A), U1.23 (SEG_D)
/SEG4: D11.2 (A), D18.2 (A), D25.2 (A), U1.21 (SEG_E)
/SEG5: D12.2 (A), D26.2 (A), U1.15 (SEG_F)
/SEG6: D13.2 (A), D19.2 (A), U1.17 (SEG_G)
/SEG7: D14.2 (A), D20.2 (A), U1.22 (SEG_DP)
GND: BZ1.2 (-), C1.2, C2.2, C3.2, J1.1, R3.2, SW1.1, TP2.1 (1_1), TP4.1 (1_1), U1.4 (GND), U1.9 (GND), U2.7 (GND)
unnamed: BZ1.1 (+), U2.15 (GPIO20)
unnamed: J1.3, U2.1 (GPIO0)
unnamed: J1.4, U2.2 (GPIO1)
unnamed: J1.5, U2.4 (GPIO3)
unnamed: J1.6, U2.3 (GPIO2)
unnamed: J1.7, U2.5 (GPIO4)
unnamed: U1.13 (CLK), U2.10 (GPIO6)
unnamed: U1.1 (DIN), U2.9 (GPIO5)
unnamed: R1.2, U1.18 (ISET)
unnamed: U1.12 (LOAD), U2.11 (GPIO7)
unnamed: SW1.2, U2.14 (GPIO10)
unnamed: R2.2, R3.1, U2.16 (GPIO21)

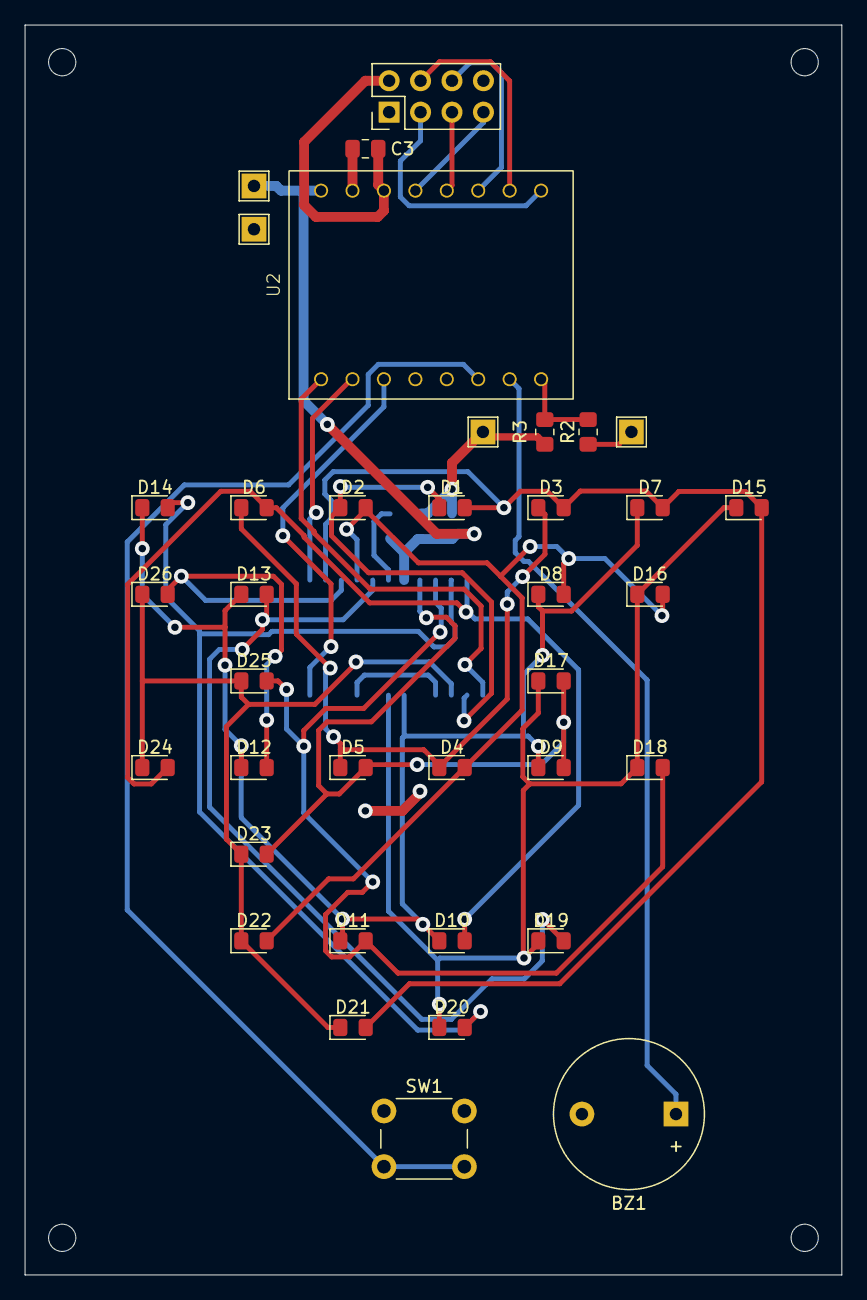
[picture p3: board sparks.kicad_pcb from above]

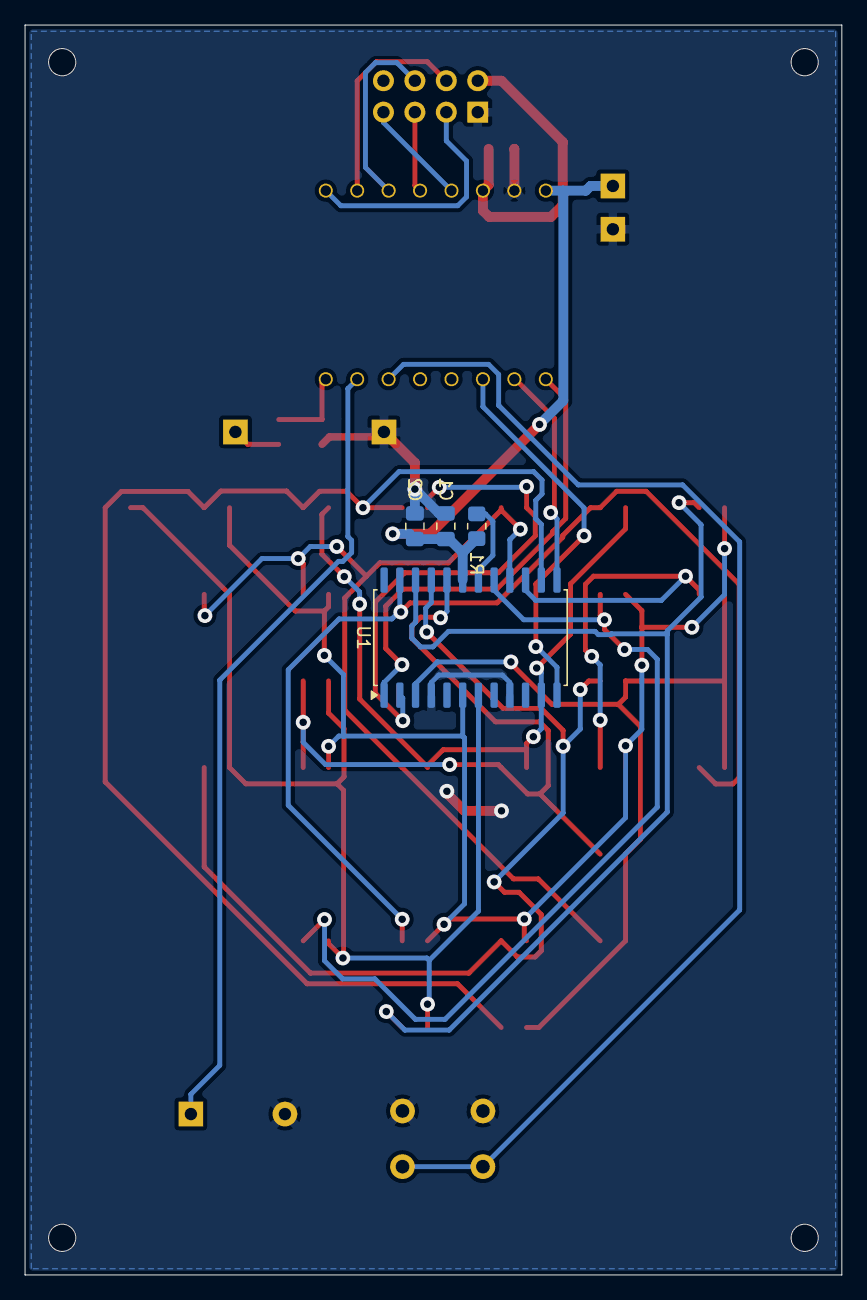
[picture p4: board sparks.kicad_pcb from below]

Board: 2 copper layers, 66.0 x 101.0 mm, 45 parts (4 on the bottom side), 29 nets.

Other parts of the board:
H1, H2, H3, H4: MountingHole_2.2mm_M2

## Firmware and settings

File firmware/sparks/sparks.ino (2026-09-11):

// ============================================================
// Sparks — a Morse code trainer and radio transmitter
// ============================================================
//
// Press the key. Sparks times what you send, walks the Morse
// tree, and lights the path on the 26-LED panel so you can see
// where the letter lives rather than just being told what it
// was.
//
// Hardware: ESP32-C3 Supermini + MAX7219 + 26 white LEDs.
// See docs/hardware.md for wiring.
//
// ------------------------------------------------------------
// RUNNING WITHOUT HARDWARE
// ------------------------------------------------------------
//
// The MAX7219 is not required. panel.h defaults to
// PANEL_SIMULATE 1, which draws the panel to the serial monitor
// instead of driving the chip. Everything else — key timing,
// decoding, adaptive speed — works identically.
//
// You can also drive it entirely from the serial monitor with
// no key wired: send '.' and '-' for symbols, space for a
// letter gap. Type `help` for the rest.
//
// Set PANEL_SIMULATE to 0 once the chip is on the board.
//
// ============================================================

#include "morse_tree.h"
#include "panel.h"
#include "key.h"
#include "sidetone.h"

// ------------------------------------------------------------
// Decoder state
// ------------------------------------------------------------

static uint8_t currentNode = MORSE_ROOT;
static bool    overrun     = false;   // more than 4 symbols sent

static char    lastLetter  = MORSE_NO_LETTER;
static String  message     = "";

// ------------------------------------------------------------

static void resetLetter() {
  currentNode = MORSE_ROOT;
  overrun     = false;
}

// ------------------------------------------------------------
// A symbol arrived: step down the tree and light the path.
// ------------------------------------------------------------

static void applySymbol(bool isDash) {
  uint8_t next = isDash ? morseStepDash(currentNode)
                        : morseStepDot(currentNode);

  if (!morseNodeValid(next)) {
    // Past the fourth level — no English letter lives here.
    // Keep accepting symbols so the letter gap still commits,
    // but remember that the result is invalid.
    overrun = true;
    Serial.println(F("  (too many symbols for a letter)"));
    return;
  }

  currentNode = next;
  panel.showPath(currentNode);

  Serial.print(F("  "));
  Serial.print(isDash ? '-' : '.');
  Serial.print(F("  -> node "));
  Serial.print(currentNode);

  char c = morseLetterAt(currentNode);
  if (c != MORSE_NO_LETTER) {
    Serial.print(F("  ("));
    Serial.print(c);
    Serial.print(')');
  } else {
    Serial.print(F("  (no letter here)"));
  }
  Serial.println();
}

// ------------------------------------------------------------
// The letter gap closed: commit whatever we landed on.
// ------------------------------------------------------------

static void commitLetter() {
  if (currentNode == MORSE_ROOT) return;   // nothing was sent

  char c = overrun ? MORSE_NO_LETTER : morseLetterAt(currentNode);

  if (c != MORSE_NO_LETTER) {
    lastLetter = c;
    message += c;

    Serial.print(F("LETTER: "));
    Serial.print(c);
    Serial.print(F("   ["));
    Serial.print(morseCodeFor(c));
    Serial.print(F("]   "));
    Serial.print(key.wpm());
    Serial.print(F(" wpm (unit "));
    Serial.print(key.unitMs());
    Serial.println(F(" ms)"));

    // Hold the finished letter lit for a moment so it registers
    // visually before the panel clears.
    panel.showPath(currentNode);
  } else {
    Serial.println(F("LETTER: ? (not a valid Morse letter)"));
    panel.clear();
    panel.show();
  }

  Serial.print(F("MESSAGE: "));
  Serial.println(message);
  Serial.println();

  resetLetter();
}

// ------------------------------------------------------------

static void commitWord() {
  if (message.length() == 0) return;
  if (message.endsWith(" "))  return;

  message += ' ';

  Serial.println(F("--- word gap ---"));
  Serial.print(F("MESSAGE: "));
  Serial.println(message);
  Serial.println();

  panel.clear();
  panel.show();
}

// ------------------------------------------------------------
// Serial commands — lets the whole thing be driven without a
// key or a panel attached.
// ------------------------------------------------------------

static void printHelp() {
  Serial.println();
  Serial.println(F("commands:"));
  Serial.println(F("  .        send a dot"));
  Serial.println(F("  -        send a dash"));
  Serial.println(F("  <space>  letter gap (commit the letter)"));
  Serial.println(F("  /        word gap"));
  Serial.println(F("  clear    clear the message"));
  Serial.println(F("  test     light every LED"));
  Serial.println(F("  wpm N    set speed, fixed (disables adaptive)"));
  Serial.println(F("  auto     re-enable adaptive speed"));
  Serial.println(F("  tone     toggle the buzzer"));
  Serial.println(F("  help     this list"));
  Serial.println();
}

static void handleSerial() {
  static String line = "";

  while (Serial.available()) {
    char c = Serial.read();

    if (c == '\n' || c == '\r') {
      line.trim();
      if (line.length() == 0) { line = ""; continue; }

      if (line == "help") {
        printHelp();
      } else if (line == "clear") {
        message = "";
        resetLetter();
        panel.clear();
        panel.show();
        Serial.println(F("message cleared"));
      } else if (line == "test") {
        panel.selfTest();
      } else if (line == "auto") {
        key.setAdaptive(true);
        Serial.println(F("adaptive speed on"));
      } else if (line == "tone") {
        sidetone.setEnabled(!sidetone.enabled());
        Serial.print(F("buzzer "));
        Serial.println(sidetone.enabled() ? F("on") : F("off"));
      } else if (line.startsWith("wpm ")) {
        int w = line.substring(4).toInt();
        if (w >= 3 && w <= 30) {
          key.setAdaptive(false);
          key.setUnitMs(1200 / w);
          Serial.print(F("fixed at "));
          Serial.print(w);
          Serial.println(F(" wpm"));
        } else {
          Serial.println(F("wpm must be 3..30"));
        }
      } else {
        Serial.print(F("unknown: "));
        Serial.println(line);
      }

      line = "";
      continue;
    }

    // Single-character symbol input, acted on immediately.
    if (c == '.') {
      applySymbol(false);
      continue;
    }
    if (c == '-') {
      applySymbol(true);
      continue;
    }
    if (c == ' ') {
      commitLetter();
      continue;
    }
    if (c == '/') {
      commitLetter();
      commitWord();
      continue;
    }

    line += c;
  }
}

// ------------------------------------------------------------

void setup() {
  Serial.begin(115200);
  delay(500);

  Serial.println();
  Serial.println(F("================================"));
  Serial.println(F(" Sparks — Morse trainer"));
  Serial.println(F("================================"));

#if PANEL_SIMULATE
  Serial.println(F("panel: SIMULATED (no MAX7219 needed)"));
  Serial.println(F("       set PANEL_SIMULATE 0 in panel.h"));
  Serial.println(F("       once the chip is wired"));
#else
  Serial.println(F("panel: MAX7219"));
#endif

  key.begin();
  panel.begin();
  sidetone.begin();

  resetLetter();

  Serial.print(F("speed: "));
  Serial.print(key.wpm());
  Serial.print(F(" wpm (unit "));
  Serial.print(key.unitMs());
  Serial.println(F(" ms), adaptive"));

  printHelp();
  Serial.println(F("ready — press the key, or type . and -"));
  Serial.println();
}

// ------------------------------------------------------------

void loop() {
  handleSerial();

  KeyEvent ev = key.poll();

  // Buzzer tracks the key directly.
  if (key.isDown()) {
    sidetone.on();
  } else {
    sidetone.off();
  }

  switch (ev) {
    case KEY_DOT:        applySymbol(false); break;
    case KEY_DASH:       applySymbol(true);  break;
    case KEY_LETTER_GAP: commitLetter();     break;
    case KEY_WORD_GAP:   commitWord();       break;
    case KEY_NONE:       break;
  }
}

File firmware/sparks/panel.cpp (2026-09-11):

#include "panel.h"

Panel panel;

// ------------------------------------------------------------
// MAX7219 registers
// ------------------------------------------------------------

#define MAX7219_REG_NOOP         0x00
#define MAX7219_REG_DIGIT0       0x01
#define MAX7219_REG_DECODE_MODE  0x09
#define MAX7219_REG_INTENSITY    0x0A
#define MAX7219_REG_SCAN_LIMIT   0x0B
#define MAX7219_REG_SHUTDOWN     0x0C
#define MAX7219_REG_DISPLAY_TEST 0x0F

// ------------------------------------------------------------

void Panel::begin() {
  clear();

#if !PANEL_SIMULATE
  pinMode(PANEL_PIN_DIN,  OUTPUT);
  pinMode(PANEL_PIN_CLK,  OUTPUT);
  pinMode(PANEL_PIN_LOAD, OUTPUT);

  digitalWrite(PANEL_PIN_CLK,  LOW);
  digitalWrite(PANEL_PIN_LOAD, HIGH);

  // Decode mode off: we drive raw segments, not BCD digits.
  // This is essential — the default would try to render numerals.
  sendRaw_(MAX7219_REG_DECODE_MODE, 0x00);

  // Scan only the rows we actually use. Fewer rows scanned means
  // a higher duty cycle per LED, so a brighter panel.
  sendRaw_(MAX7219_REG_SCAN_LIMIT, PANEL_DIGITS - 1);

  sendRaw_(MAX7219_REG_INTENSITY, brightness_);
  sendRaw_(MAX7219_REG_DISPLAY_TEST, 0x00);
  sendRaw_(MAX7219_REG_SHUTDOWN, 0x01);   // 1 = normal operation
#endif

  show();
}

// ------------------------------------------------------------

void Panel::clear() {
  for (uint8_t i = 0; i < PANEL_DIGITS; i++) {
    buffer_[i] = 0;
  }
}

// ------------------------------------------------------------

void Panel::setNode(uint8_t node, bool on) {
  if (!morseNodeValid(node)) return;

  LedAddr a = MORSE_NODE_LED[node];
  if (a.dig == MORSE_NO_LED) return;      // root, or an empty slot
  if (a.dig >= PANEL_DIGITS) return;

  if (on) {
    buffer_[a.dig] |= (1 << a.seg);
  } else {
    buffer_[a.dig] &= ~(1 << a.seg);
  }
}

// ------------------------------------------------------------

void Panel::showNodeOnly(uint8_t node) {
  clear();
  setNode(node, true);
  show();
}

// ------------------------------------------------------------
// Walk back up to the root, lighting every node on the way.
//
// Parent of node n is (n - 1) / 2, which is why breadth-first
// numbering was worth the small awkwardness in the table.
// ------------------------------------------------------------

void Panel::showPath(uint8_t node) {
  clear();

  uint8_t n = node;
  while (morseNodeValid(n) && n != MORSE_ROOT) {
    setNode(n, true);
    n = (n - 1) / 2;
  }

  show();
}

// ------------------------------------------------------------

void Panel::setBrightness(uint8_t value) {
  if (value > 15) value = 15;
  brightness_ = value;

#if !PANEL_SIMULATE
  sendRaw_(MAX7219_REG_INTENSITY, brightness_);
#endif
}

// ------------------------------------------------------------

void Panel::show() {
#if PANEL_SIMULATE
  renderSerial_();
#else
  for (uint8_t d = 0; d < PANEL_DIGITS; d++) {
    sendRaw_(MAX7219_REG_DIGIT0 + d, buffer_[d]);
  }
#endif
}

// ------------------------------------------------------------

void Panel::selfTest() {
  Serial.println(F("[PANEL] Self test — all LEDs on"));

  for (uint8_t i = 0; i < PANEL_DIGITS; i++) {
    buffer_[i] = 0xFF;
  }
  show();

  delay(1000);

  clear();
  show();
}

// ------------------------------------------------------------
// Bit-banged SPI. The MAX7219 wants 16 bits: address then data,
// MSB first, latched on a rising edge of LOAD.
//
// Not using the SPI peripheral here because the CC1101 owns it,
// and bit-banging three pins costs nothing at this rate.
// ------------------------------------------------------------

void Panel::sendRaw_(uint8_t reg, uint8_t data) {
#if !PANEL_SIMULATE
  digitalWrite(PANEL_PIN_LOAD, LOW);

  shiftOut(PANEL_PIN_DIN, PANEL_PIN_CLK, MSBFIRST, reg);
  shiftOut(PANEL_PIN_DIN, PANEL_PIN_CLK, MSBFIRST, data);

  digitalWrite(PANEL_PIN_LOAD, HIGH);
#else
  (void)reg;
  (void)data;
#endif
}

// ------------------------------------------------------------
// Simulation: draw the tree to the serial monitor.
//
// Laid out like the physical panel — dots to the right, dashes
// to the left — so what you read here matches what the board
// will look like.
// ------------------------------------------------------------

void Panel::renderSerial_() {
#if PANEL_SIMULATE
  auto lit = [&](uint8_t node) -> bool {
    if (!morseNodeValid(node)) return false;
    LedAddr a = MORSE_NODE_LED[node];
    if (a.dig == MORSE_NO_LED || a.dig >= PANEL_DIGITS) return false;
    return buffer_[a.dig] & (1 << a.seg);
  };

  // A lit letter is shown in brackets, an unlit one as a dot.
  auto cell = [&](uint8_t node) {
    char c = morseLetterAt(node);
    if (c == MORSE_NO_LETTER) {
      Serial.print(F("    "));
      return;
    }
    if (lit(node)) {
      Serial.print('[');
      Serial.print(c);
      Serial.print(']');
    } else {
      Serial.print(' ');
      Serial.print(c);
      Serial.print(' ');
    }
    Serial.print(' ');
  };

  Serial.println();
  Serial.println(F("  ---- panel ----"));

  // Level 1: E T
  Serial.print(F("   L1: "));
  cell(1); cell(2);
  Serial.println();

  // Level 2: I A N M
  Serial.print(F("   L2: "));
  for (uint8_t n = 3; n <= 6; n++) cell(n);
  Serial.println();

  // Level 3: S U R W D K G O
  Serial.print(F("   L3: "));
  for (uint8_t n = 7; n <= 14; n++) cell(n);
  Serial.println();

  // Level 4
  Serial.print(F("   L4: "));
  for (uint8_t n = 15; n <= 30; n++) cell(n);
  Serial.println();
  Serial.println();
#endif
}

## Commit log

2026-09-11 Scaffold project structure, documentation and BOM
    Organize the repository into bom/, docs/, firmware/, hardware/,
    mechanical/ and media/, following the layout used in robo-sumo-uno.
    Document the design as it currently stands:
    - The 26-LED panel is the International Morse tree, one LED per
    letter, all white. The dot/dash distinction is engraved into the
    connecting arms rather than encoded by LED colour.
    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
    [bom.csv]
2026-09-11 Add trainer firmware and KiCad reference
    Implement the Morse trainer as five modules: tree geometry and
    addressing, key timing with adaptive speed, the MAX7219 panel
    driver, and the buzzer sidetone.
    Decoding is a tree walk rather than a table lookup, so the node
    being decoded is also the LED to light — the panel shows the
    path building up as a letter is sent.
    The panel driver falls back to drawing on the serial monitor
    when PANEL_SIMULATE is set, so the firmware runs and is fully
    testable before the MAX7219 arrives.
    Replace the old CC1101 bench sketch, which predated the panel
    design and only sent a hardcoded HELLO.
    Document the KiCad symbols, footprints and MAX7219 pinout
    verified aga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
    [bom.csv, sparks.kicad_pcb, sparks.kicad_sch]
2026-09-11 Add ESP32-C3 SuperMini KiCad library
    Vendor the symbol, footprint and 3D model for the ESP32-C3
    SuperMini, which is absent from the KiCad stock libraries. Files
    are unmodified from upstream.
    Record the provenance and the licensing caveat in the library
    README: the source repository carries no licence file, so the
    material is under default copyright and is vendored here for
    personal use only.
    Note in the README that some SuperMini pinout diagrams in
    circulation are x-mirrored relative to the correct orientation,
    so a disagreeing reference image is not evidence the symbol is
    wrong.
    Ignore KiCad 10's .history autosave store, which is a nested git
    repository holding generated state rather tha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
2026-09-11 Add TP4056 and CC1101 libraries, start the schematic
    Vendor the TP4056 breakout symbol and footprint, and a CC1101
    module symbol converted from the legacy KiCad 5 .lib format.
    Neither part is in the KiCad stock libraries.
    Do not vendor the upstream CC1101 footprint: it is a single
    column of 8 pads at 2.0 mm pitch, belonging to a bare
    Homematic-style board. The module used here has 8 pins in two
    rows of four at 2.54 mm, so a stock PinHeader_2x04_P2.54mm
    footprint is correct instead.
    Flag the TP4056 footprint as unverified. Its pad spacing is
    irregular rather than on a 2.54 mm grid, so it is specific to
    one board revision and may not fit a module from another
    seller. Measure before committin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
    [sparks.kicad_sch]
2026-09-13 Complete the schematic
    Wire the full circuit: the 26-LED matrix, the MAX7219 driver, the
    ESP32-C3, the CC1101 socket, the TP4056 charger and the battery
    sense divider. ERC passes with no errors.
    The LED matrix is verified against the Morse tree by exporting the
    netlist and checking every diode: all 26 sit on the SEG/DIG pair
    their letter's code requires, including the gaps at SEG3 and SEG5
    in the DIG3 row where the non-English letters would be.
    Set the battery divider to 220k/220k, halving cell voltage into the
    ADC range for about 9.5 uA of drain.
    Choose the remaining parts: a 12 mm magnetic buzzer, a 6 mm tactile
    switch, and a 102050 1000 mAh LiPo pouch giving roughly seven hours
    in trai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
    [bom.csv, sparks.kicad_sch]
2026-09-13 Switch to the HW-357 combined charger and boost module
    Power now comes from an HW-357: a TP4056 charger and an MT3608
    boost converter on one board with its own micro-USB socket. Its
    IN+/IN- pads are left unconnected, since charging goes through
    that socket.
    This resolves the open supply question. The +5V net carries a
    genuine regulated 5 V instead of raw cell voltage, so the MAX7219
    keeps proper headroom above the white LEDs' ~3.4 V forward drop
    and the panel no longer dims as the battery drains.
    Record the cost: a boost draws more current than it supplies, so
    delivering 139 mA at 5 V pulls about 190 mA from the cell and the
    1000 mAh pack gives roughly five hours rather than seven.
    Warn t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
    [bom.csv, sparks.kicad_sch]
2026-09-13 Place all components on the PCB
    Arrange the 26 LEDs as the Morse tree from the reference image:
    dots branch right, dashes branch left, and each level steps
    perpendicular to the last. That alternating geometry keeps the
    panel to 54 x 44 mm, where a conventional top-down tree would
    have sprawled to 116 mm and been unusable in the hand.
    Put the MAX7219 on the back, centred beneath the panel, with its
    decoupling and RSET beside it. The front face therefore carries
    nothing but LEDs. Everything else - the CC1101 socket, ESP32-C3,
    power module, key and buzzer - sits below the panel on the front.
    Board outline is 66 x 94 mm.
    Record in the decision log why the board has to be double-sided:
    routing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
    [led_placement.csv, part_placement.csv, sparks.kicad_pcb]
2026-09-13 Correct the panel to a 7x7 grid
    The previous placement generated an extra empty column, because X
    sat on an odd half-step while every other letter fell on a whole
    one. The panel is a 7x7 grid with 26 of the 49 cells filled:
    O M T E I S H
    Q G - - U V -
    - Z - - F - -
    Y K N A R L -
    - C - - - - -
    - X D W P - -
    - - B J - - -
    Row 0 is the repeated-symbol spine, reading H S I E outward to the
    right and T M O to the left. Row 3 is the second spine, where the
    code switches symbol once: A R L rightward, N K Y leftward.
    Everything else hangs off those two rows, which is why the middle
    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
    [led_placement.csv, part_placement.csv, sparks.kicad_pcb]
2026-09-13 Mount the CC1101 socket at the board edge
    The module plugs into the socket and overhangs the board entirely,
    so the board carries only the 2x4 socket rather than the module's
    full 28 mm length. The body and antenna extend past the top edge,
    away from the user.
    This keeps the board at 66 x 101 mm. Placing the module on the
    board instead would have pushed it to 66 x 123 mm, since the
    antenna exits the short edge opposite the pin header and the whole
    module would have needed room above the panel.
    Note in board_outline.txt that the module is held only by its eight
    pins, so the case should brace it.
    [part_placement.csv, sparks.kicad_pcb]
2026-09-13 Rotate the CC1101 socket so the antenna points away from the user
    PinSocket_2x04_P2.54mm_Vertical places 4 rows along Y and 2 columns
    along X at rotation 0, not the other way round. With the socket
    unrotated the module's length ran horizontally and the antenna
    pointed out the side of the board.
    Rotating the socket 90 degrees puts the four-pin row along X, so the
    module's length runs vertically and the antenna extends past the top
    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
    [part_placement.csv, sparks.kicad_pcb]
2026-09-13 Add a CC1101 socket footprint with the module's own pin numbering
    The stock PinSocket_2x04 numbers pads 2/1, 4/3, 6/5, 8/7 across the
    two rows, which put pin 1 on the outward-facing row. The module has
    pin 1 (GND) on the row nearest the board and pin 2 (3V3) on the
    outward row.
    No rotation of the stock footprint produces that arrangement: 90 and
    270 turn it sideways into two columns of four, and 180 swaps the
    columns as well as the rows. It needs a mirror, which a footprint
    cannot do without changing layers.
    Add Sparks:CC1101_Socket_2x04 with pad positions written explicitly
    so that at rotation 0 the top row is 2 4 6 8 and the bottom row,
    against the board, is 1 3 5 7.
    Register the Sparks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
    [sparks.kicad_pcb, sparks.kicad_sch]
2026-09-13 Fix the CC1101 socket pad layout on the board
    The PCB carried pad coordinates copied from the stock footprint
    when the netlist was last imported, so the socket rendered as two
    columns of four with pin 1 on the outward row. Updating from the
    schematic reapplied that geometry rather than reading the project
    library.
    Rewrite the eight pad positions directly in the board file: the top
    row, away from the board, is 2 4 6 8 and the bottom row, against
    the board, is 1 3 5 7. Pin 1 is GND and pin 2 is 3V3, matching the
    module.
    Leave the schematic symbol's rotation alone. Changing it moves the
    pins off their wires and disconnects GND and 3V3; the symbol's
    angle is cosmetic and does not determine the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
    [sparks.kicad_pcb]
2026-09-13 Use a stock pin header for the CC1101 socket, and route DIG0
    Replace the CC1101 connector with the stock
    PinHeader_2x04_P2.54mm_Vertical at 90 degrees, which gives the
    module's own pin arrangement directly: the top row, away from the
    board, is 2 4 6 8 and the bottom row, against the board, is
    1 3 5 7, with pin 1 on GND and pin 2 on 3V3.
    Drop the custom footprint added earlier. It was built on the
    assumption that no rotation of a stock part could produce this
    layout, which came from testing rotations of the socket footprint
    rather than the header - the two number their pads differently.
    Route the first track: D1 to D2 on DIG0, 0.4 mm on the front
    layer, 9 mm of copper over three segments. T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
    [sparks.kicad_pcb, sparks.kicad_sch]
2026-09-13 Clear all routing ahead of autorouting
    Remove 177 track segments and 15 vias. Placement, the ground pour,
    the board outline and all 45 footprints are untouched.
    Manual routing of the matrix proved impractical: the LEDs are
    arranged by the Morse tree's geometry while the nets are grouped by
    tree level, so same-net LEDs sit far apart and every net has to
    weave through the others. Freerouting will be given the clean board
    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
    [sparks.kicad_pcb, sparks.kicad_sch]
2026-09-13 Autoroute the board
    Route all 29 nets with Freerouting: 391 segments, 1476 mm of copper
    and 49 vias across both layers, with no unrouted nets and no
    clearance violations.
    Manual routing had stalled because the LEDs are positioned by the
    Morse tree's geometry while the nets are grouped by tree level, so
    same-net LEDs sit far apart and each net has to weave through the
    others.
    Widen the last 0.3 mm segments left over from hand routing to the
    0.4 mm minimum, and narrow the ground pour's thermal spokes to
    0.35 mm so every GND pad forms a complete two-spoke relief. DRC
    passes.
    [sparks.dsn, sparks.kicad_pcb]
